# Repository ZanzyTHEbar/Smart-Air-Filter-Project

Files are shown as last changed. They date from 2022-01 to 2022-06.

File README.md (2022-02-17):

# :man_technologist:

# Purbright Controller

# :cat: Purbright Controller :cat2:

# Purbright Controller README

This repo is dedicated to the **Purbright Controller**, an automated system for purifying cat litter air.

# WHAT IS THIS PROJECT

This project is dedicated to designing PCB and programming files to bring the Purbright product to mass manufacturing.

# Things to Do

**__Hardware__**

- [x] Formulate project as PlatformIO
- [x] Integrate the PCB schematic layout
- [x] Integrate a BOM parts list for PCB
- [x] Integrate a Pick and Place file
- [ ] Integrate Panelised PCB gerber files
- [ ] Integrate SPI SRAM chip instead of SD Card
- [ ] Integrate speakers for audio feedback

**__Software__**

- [x] Implement proper memory management
- [ ] Implement proper error handling&logging
- [ ] Implement proper documentation
- [ ] Implement proper debugging for testing
- [ ] Add custom sounds for speakers
- [x] implement code as proper custom library
- [ ] implement dual core system archtecture
        --> Networking on one core and Application code on the other (esp32 is dual core)

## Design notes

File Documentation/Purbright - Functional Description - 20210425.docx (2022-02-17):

This document serves to describe the necessary functionality of the electronics that control the Purfect cat litter box.

# 1. Overview

The device filters dirty air by drawing air from the cat litter box by means of a Venturi. The water circulation flow is generated with a pump that pumps from a water reservoir back into the same reservoir. The venturi is located on the high-pressure side of the pump (output). The pump is activated when motion is detected. The pump stops automatically after a certain set time. When the manual mode is selected, the pump runs continuously.
The touch buttons are:
a. 1 button. ON/OFF switching
b. 2 buttons +/-. menu scrolling and raising/lowering automatic ON-time.

c. 1 button: selection between auto/man or settings menu after long press.

# 2. Components

a. Water pump (preferably a 5VDC version)
b. Venturi nozzle
c. Motion detection sensor
d. PCB with relay for the water pump
e. 4 touch sensors for menu control
f. NeoPixel LED for menu indication
g. speaker

# 3. Electric Diagram

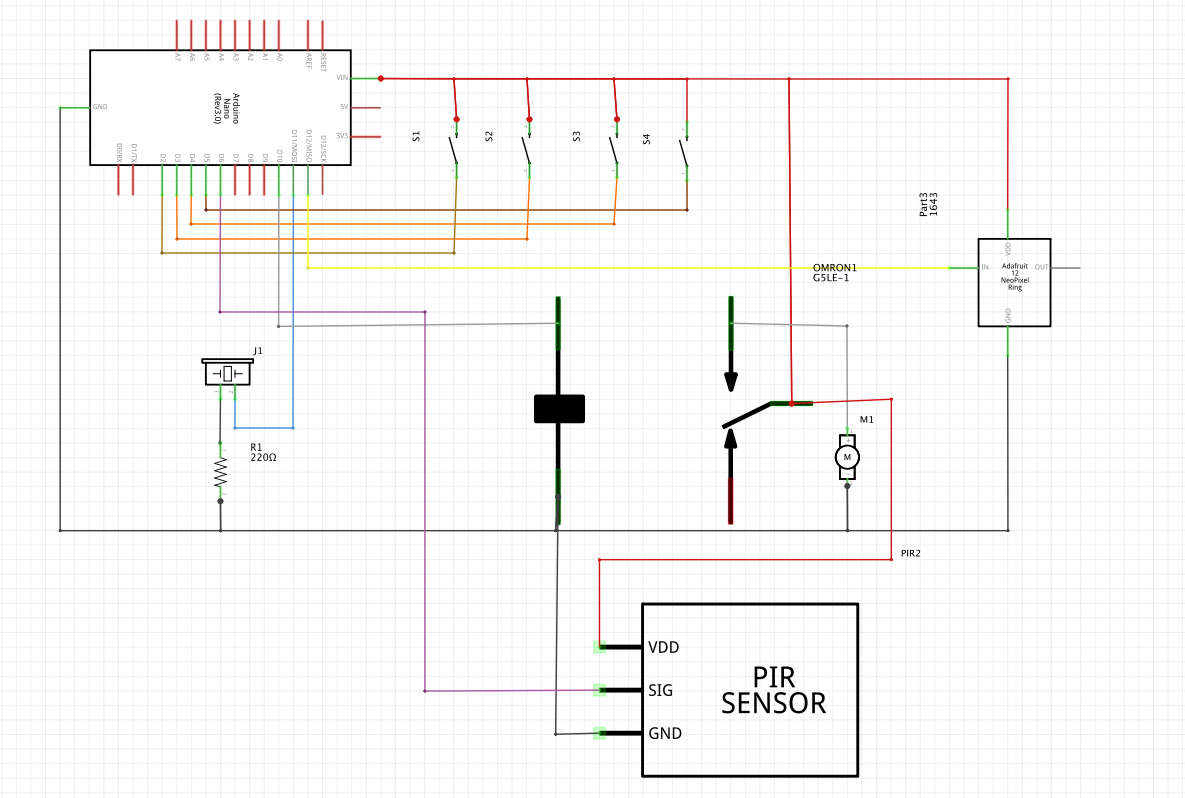
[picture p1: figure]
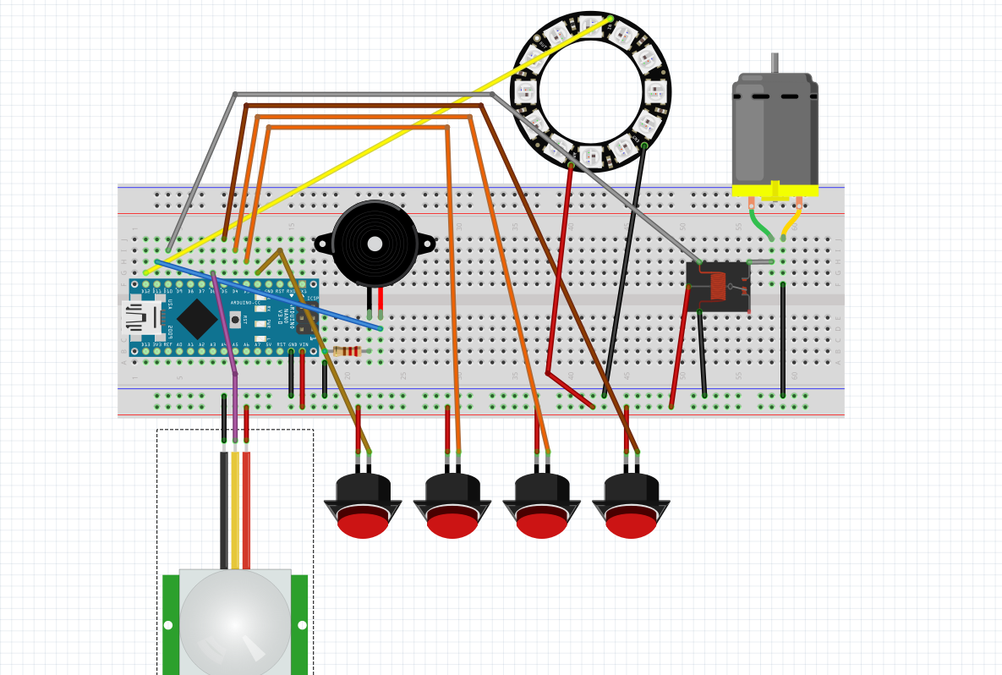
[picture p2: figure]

# 4. Shell

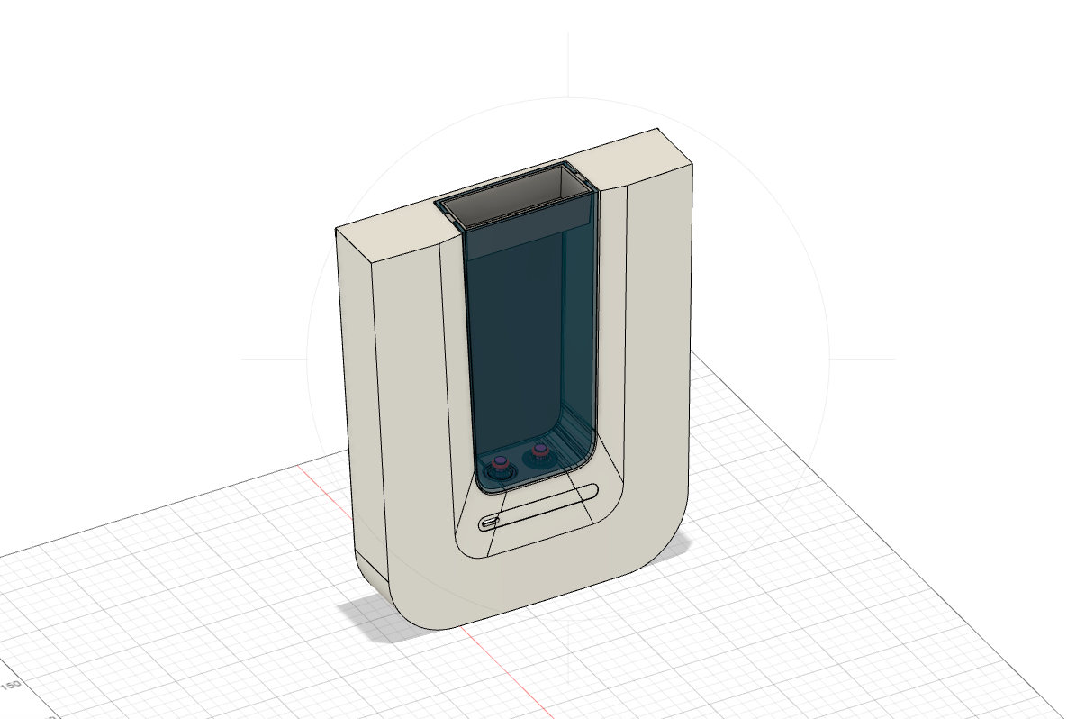
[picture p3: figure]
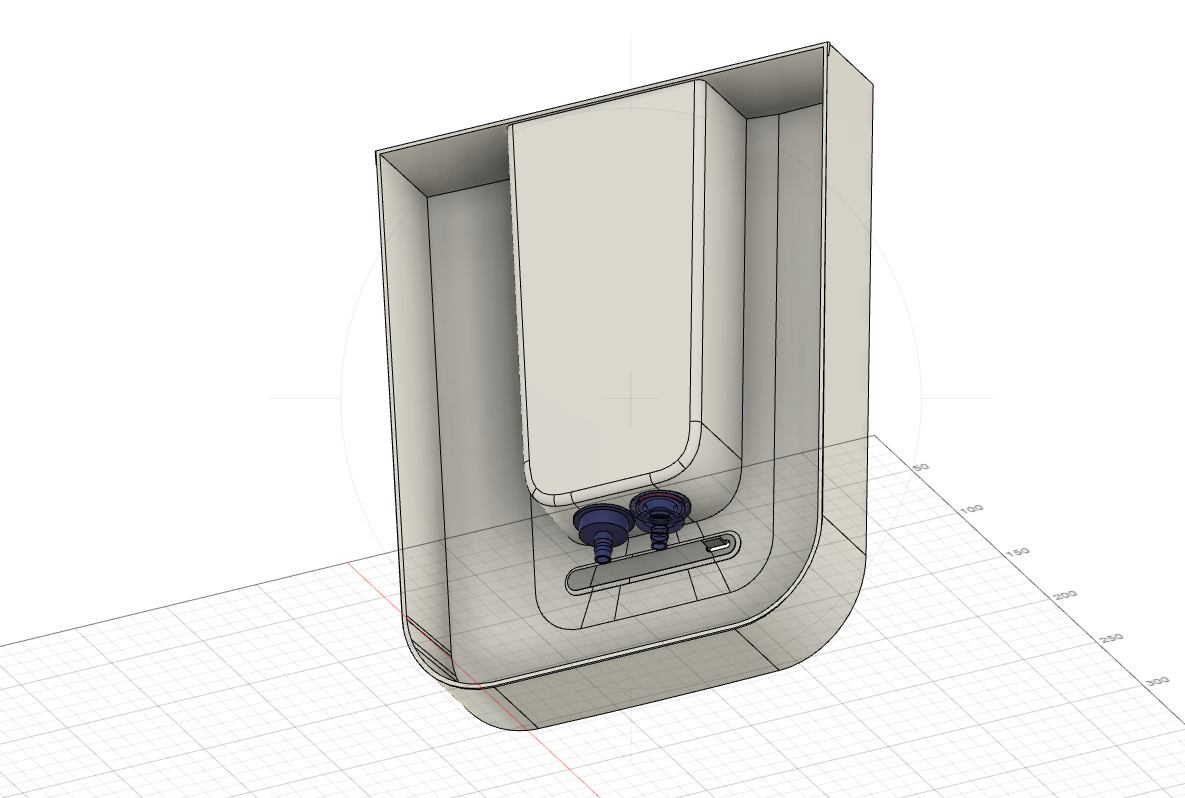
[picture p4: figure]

Location of touch buttons

Location of NeoPixel

# 5. Specifications

a. All components external to the PCB should be easily replaceable with a connector (Touch buttons, NeoPixel, Motion Sensor)
b. Power rating should be 5VDC.
c. An extra USB-C should be added for the power supply since the onboard USB-C cannot provide enough current for the water pump.
d. The possibility to update the device is required. (SD > Bluetooth > Wifi) The PCB should probably have the need for an (integrated) SD card. This would also allow for a storage of sound clips.
e. The capacitive touch buttons are located on the inside of the shell.

# 6. Extra Remarks

a. The current project is based on a Seeeduino/Arduino Nano but any suggestions is welcome. Arduino was chosen for the programmability.
b. Programming can be done by us if the Arduino technology is chosen. If not, when cheaper solution is provided, this document will be updated with a more extensive description of the workflow.
c. If for CE approval a hardware ON/OFF (vs the soft ON/OFF), the please include it.
d. The project was conceptualized with Arduino and

Purbright BV Vaderlandstraat 37, B-2610 Wilrijk, Belgium | VAT: BE 0750.606.388 M: +32 477 28 00 77 | E: hello@purbright.com | www.purbright.com

Functional Description Electronics

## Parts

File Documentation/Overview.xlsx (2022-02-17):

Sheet: Parts
 |  |  |  |  | 17 | 49.10 €
Group | Part | Brand | Model | Price | Qty | Tot | Supplier | Comments
Electronic | Board | Seeeduino Nano | SS-102010268 | 8.95 € | 1 | 8.95 € | www.kiwi-electronics.nl
Electronic | Relay | Grove | SS-103020005 | 3.50 € | 1 | 3.50 € | www.kiwi-electronics.nl
Electronic | LED | NeoPixel Ring | ADA-1643 | 8.95 € | 1 | 8.95 € | www.kiwi-electronics.nl
Electronic | Motion Sensor | Grove | SS-101020353 | 5.95 € | 1 | 5.95 € | www.kiwi-electronics.nl | PIR Mini
Electronic | Touch Sensor | Grove | SS-101020037 | 4.95 € | 4 | 19.80 € | www.kiwi-electronics.nl
Electronic | Speaker |  | ADA-1891 | 1.95 € | 1 | 1.95 € |  | Thin Plastic Speaker with Wires - 8 ohm 0.25W
Electronic | Pump |  |  |  | 1 | 0.00 € |  | 3-6V RC Water Pump
Water | Tubes |  |  |  |  | 0.00 €
Water | T-Connection |  |  |  | 1 | 0.00 € |  | This needs to be a venturi
Water | O-ring |  |  |  | 2 | 0.00 € |  | Reservoir closing
Water | Spring |  |  |  | 2 | 0.00 € |  | Reservoir closing
Water | Closing Pin |  |  |  | 2 | 0.00 € |  | Reservoir closing
 |  |  |  |  |  | 0.00 €
 |  |  |  |  |  | 0.00 €
 |  |  |  |  |  | 0.00 €
 |  |  |  |  |  | 0.00 €
 |  |  |  |  |  | 0.00 €
 |  |  |  |  |  | 0.00 €
 |  |  |  |  |  | 0.00 €
 |  |  |  |  |  | 0.00 €
 |  |  |  |  |  | 0.00 €
 |  |  |  |  |  | 0.00 €
 |  |  |  |  |  | 0.00 €
 |  |  |  |  |  | 0.00 €
 |  |  |  |  |  | 0.00 €
 |  |  |  |  |  | 0.00 €
 |  |  |  |  |  | 0.00 €
 |  |  |  |  |  | 0.00 €
 |  |  |  |  |  | 0.00 €
 |  |  |  |  |  | 0.00 €
 |  |  |  |  |  | 0.00 €
 |  |  |  |  |  | 0.00 €
 |  |  |  |  |  | 0.00 €
 |  |  |  |  |  | 0.00 €
 |  |  |  |  |  | 0.00 €
 |  |  |  |  |  | 0.00 €
 |  |  |  |  |  | 0.00 €
 |  |  |  |  |  | 0.00 €
 |  |  |  |  |  | 0.00 €
 |  |  |  |  |  | 0.00 €
 |  |  |  |  |  | 0.00 €
 |  |  |  |  |  | 0.00 €
 |  |  |  |  |  | 0.00 €
 |  |  |  |  |  | 0.00 €
 |  |  |  |  |  | 0.00 €
 |  |  |  |  |  | 0.00 €
 |  |  |  |  |  | 0.00 €
 |  |  |  |  |  | 0.00 €
 |  |  |  |  |  | 0.00 €
 |  |  |  |  |  | 0.00 €
 |  |  |  |  |  | 0.00 €
 |  |  |  |  |  | 0.00 €
 |  |  |  |  |  | 0.00 €
 |  |  |  |  |  | 0.00 €
 |  |  |  |  |  | 0.00 €
 |  |  |  |  |  | 0.00 €
 |  |  |  |  |  | 0.00 €
 |  |  |  |  |  | 0.00 €
 |  |  |  |  |  | 0.00 €
 |  |  |  |  |  | 0.00 €
 |  |  |  |  |  | 0.00 €
 |  |  |  |  |  | 0.00 €
 |  |  |  |  |  | 0.00 €
 |  |  |  |  |  | 0.00 €
 |  |  |  |  |  | 0.00 €
 |  |  |  |  |  | 0.00 €
 |  |  |  |  |  | 0.00 €
 |  |  |  |  |  | 0.00 €
 |  |  |  |  |  | 0.00 €
 |  |  |  |  |  | 0.00 €
 |  |  |  |  |  | 0.00 €
 |  |  |  |  |  | 0.00 €
 |  |  |  |  |  | 0.00 €
 |  |  |  |  |  | 0.00 €
 |  |  |  |  |  | 0.00 €
 |  |  |  |  |  | 0.00 €
 |  |  |  |  |  | 0.00 €
 |  |  |  |  |  | 0.00 €
 |  |  |  |  |  | 0.00 €
 |  |  |  |  |  | 0.00 €
 |  |  |  |  |  | 0.00 €
 |  |  |  |  |  | 0.00 €
 |  |  |  |  |  | 0.00 €
 |  |  |  |  |  | 0.00 €
 |  |  |  |  |  | 0.00 €
 |  |  |  |  |  | 0.00 €
 |  |  |  |  |  | 0.00 €
 |  |  |  |  |  | 0.00 €
 |  |  |  |  |  | 0.00 €
 |  |  |  |  |  | 0.00 €
 |  |  |  |  |  | 0.00 €
 |  |  |  |  |  | 0.00 €
 |  |  |  |  |  | 0.00 €
 |  |  |  |  |  | 0.00 €
 |  |  |  |  |  | 0.00 €
 |  |  |  |  |  | 0.00 €
 |  |  |  |  |  | 0.00 €
 |  |  |  |  |  | 0.00 €
 |  |  |  |  |  | 0.00 €
 |  |  |  |  |  | 0.00 €
 |  |  |  |  |  | 0.00 €
 |  |  |  |  |  | 0.00 €
 |  |  |  |  |  | 0.00 €
 |  |  |  |  |  | 0.00 €
 |  |  |  |  |  | 0.00 €
 |  |  |  |  |  | 0.00 €
 |  |  |  |  |  | 0.00 €
 |  |  |  |  |  | 0.00 €
 |  |  |  |  |  | 0.00 €

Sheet: IO
IO | Description | Type | Tech | Comment
IN | Motion Detection | Digitial
IN | Button 1: On/Off | Digitial | Capacitive?
IN | Button 2: Auto/man | Digitial | Capacitive?
IN | Button 3: + | Digitial | Capacitive?
IN | Button 4: - | Digitial | Capacitive?
OUT | Relay? | Digital |  | for 3-6V pump
OUT | NeoPixel |  |  | State indication
OUT | Speaker

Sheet: FDS
General
After detection of motion, the device starts a timed pump to pull water from the reservoir. This water gets mixed with air from the box that gets sucked in with a venturi.
This water -air mixture gets pumped back into the reservoir.
Startup
1. When the device is connected into the power socket, a power LED turns on.
2. With the ON/OFF button the device is activated and goes into automatic mode.
3. In automatic mode, motion is detected and a timed pump starts.
3.1. When motion is detected, another LED indicates the presence
3.2. During operation, a 3rd LED indicates wether the pump is on or off
4. With the Man/AUT button, the device can be put in manual mode where the pump is in continuous operation
5. By pressing the '+' button, the devices indicates the time settings and by pressing it again, time can be added (example: in blocks of 2m) to the automtic mode.
6. By pressing the '-' button, the devices indicates the time settings and by pressing it again, time can be subtracted (example: in blocks of 2m) from the automtic mode.
Notes
5&6 keep the operation mode going

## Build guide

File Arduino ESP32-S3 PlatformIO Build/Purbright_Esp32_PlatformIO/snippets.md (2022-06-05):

# HTML Snippets

```html
<div class="container">
    <div class="row">
        <div class="col-md-12">
            <h1>Hello World</h1>
        </div>
    </div>
</div>
```

## Calculate the range of Wifi signal strength

´´´txt
Signal transmission in ft^2 = ((dBm + 4,000) - 2,000) / 42.7

4,000 = nominal base dB of average consumer grade WIFI antenna
2,000 = Nominal base dB of peak signal interference
42.7 = a constant for conversion to square feet
´´´

```cpp
int signal_range = ((dBm + 4,000) - 2,000) / 42.7;

WiFi.setOutputPower(dBm);
From the point of view of the client:
a: How low is to low - when is the client not able to see the server
b: How close to this lowest point are we willing to go?

1. Client tells the server when it needs a stronger signal - do this in levels
2. Server lowers signal by a certain value each time frame 
3. Every x amount of time based on how long device can be without connection - it will pulse the signal at max sending out a wake up call to devices that have potentially lost connection
```

```cpp
if (!PRODUCTION) {
  // do development stuff
}
```

## Useful Links

[Wifi QR code generator](https://qifi.org/)

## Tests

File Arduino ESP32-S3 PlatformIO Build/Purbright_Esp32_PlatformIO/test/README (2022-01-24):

This directory is intended for PlatformIO Unit Testing and project tests.

Unit Testing is a software testing method by which individual units of
source code, sets of one or more MCU program modules together with associated
control data, usage procedures, and operating procedures, are tested to
determine whether they are fit for use. Unit testing finds problems early
in the development cycle.

More information about PlatformIO Unit Testing:
- https://docs.platformio.org/page/plus/unit-testing.html

pio\build\esp32dev\src\main.cpp.o:main.cpp:(.text._ZN20ESPAsync_WiFiManager11connectWifiERK6StringS2_+0x0): first defined here
.pio\build\esp32dev\lib142\libPurBrightLib.a(neopixel.cpp.o): In function `ESPAsync_WiFiManager::reconnectWifi()':
neopixel.cpp:(.text._ZN20ESPAsync_WiFiManager13reconnectWifiEv+0x0): multiple definition of `ESPAsync_WiFiManager::reconnectWifi()'

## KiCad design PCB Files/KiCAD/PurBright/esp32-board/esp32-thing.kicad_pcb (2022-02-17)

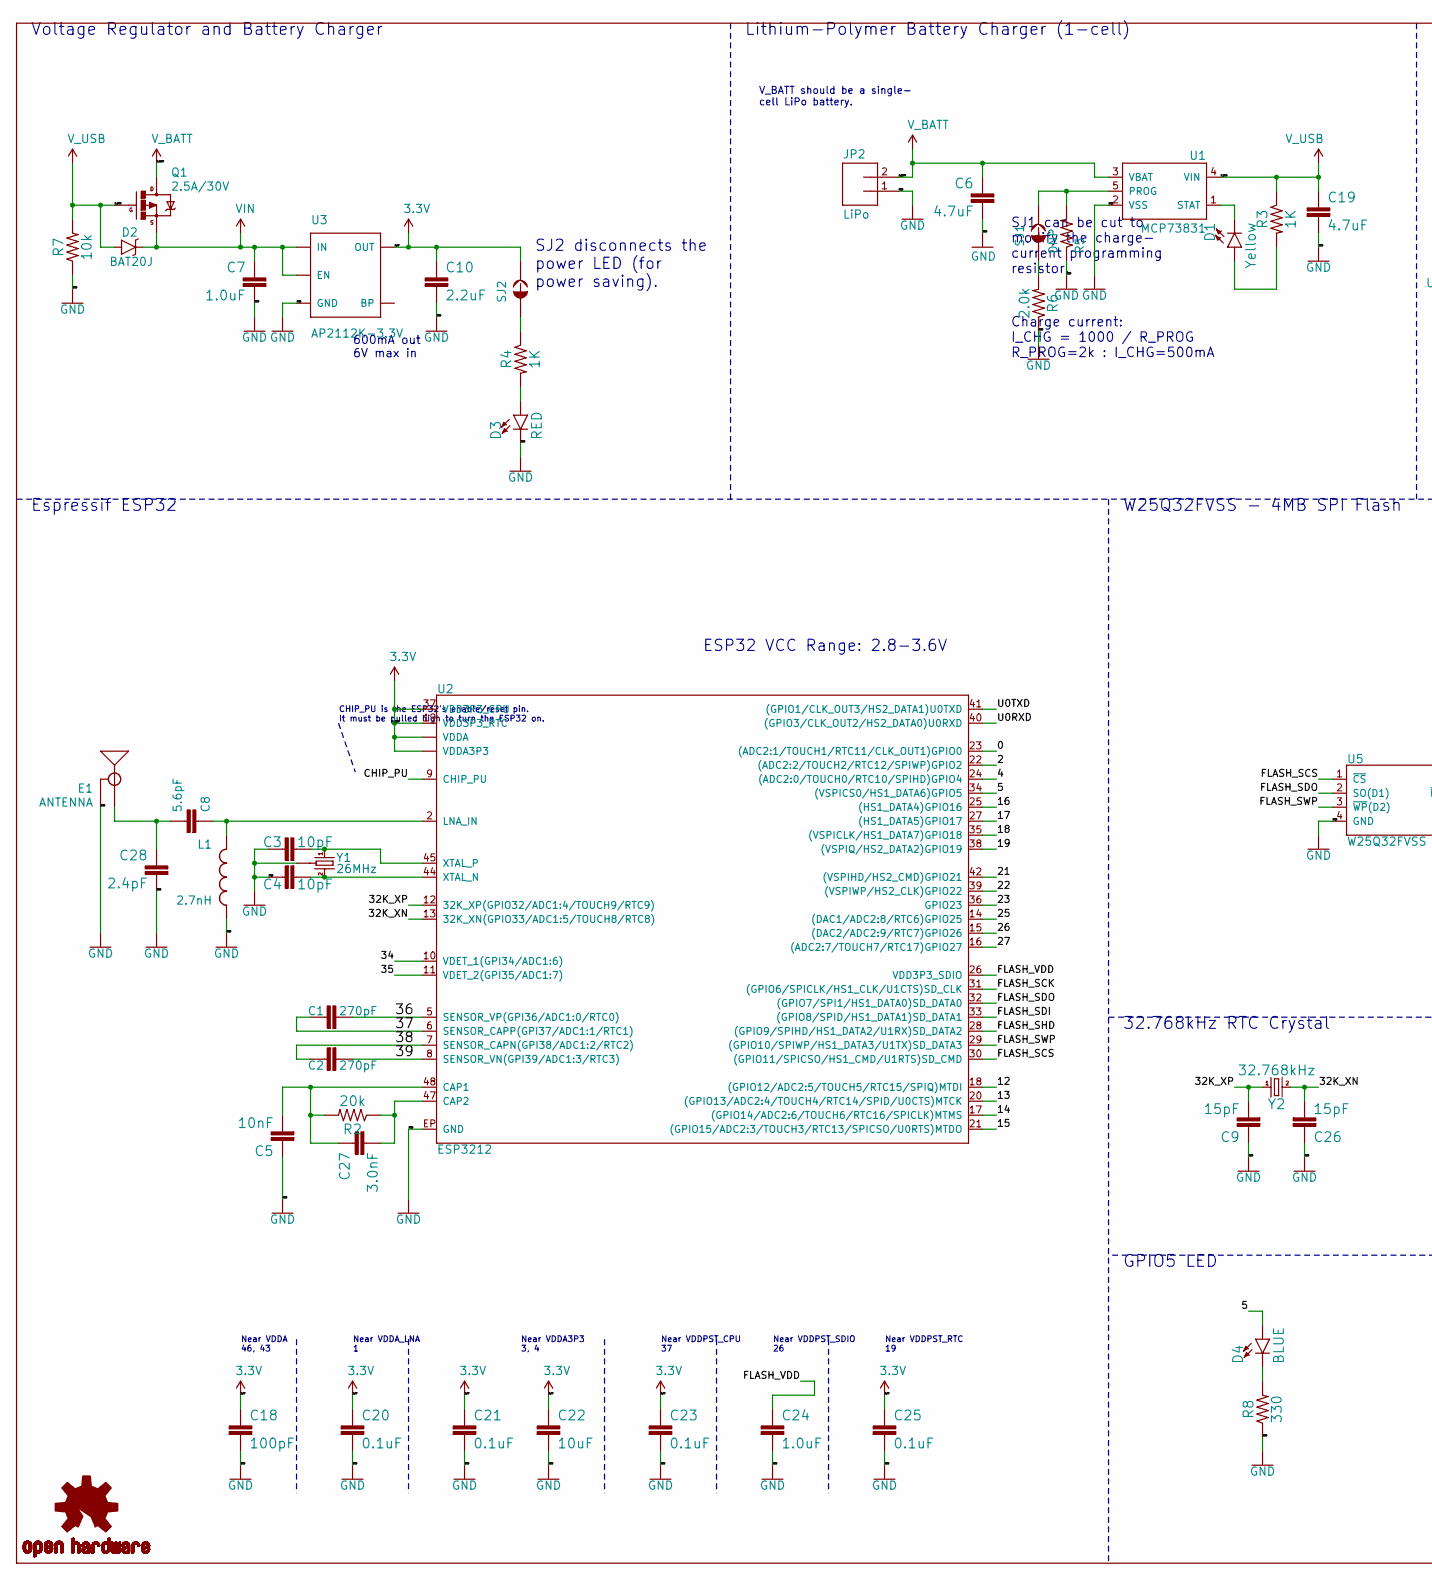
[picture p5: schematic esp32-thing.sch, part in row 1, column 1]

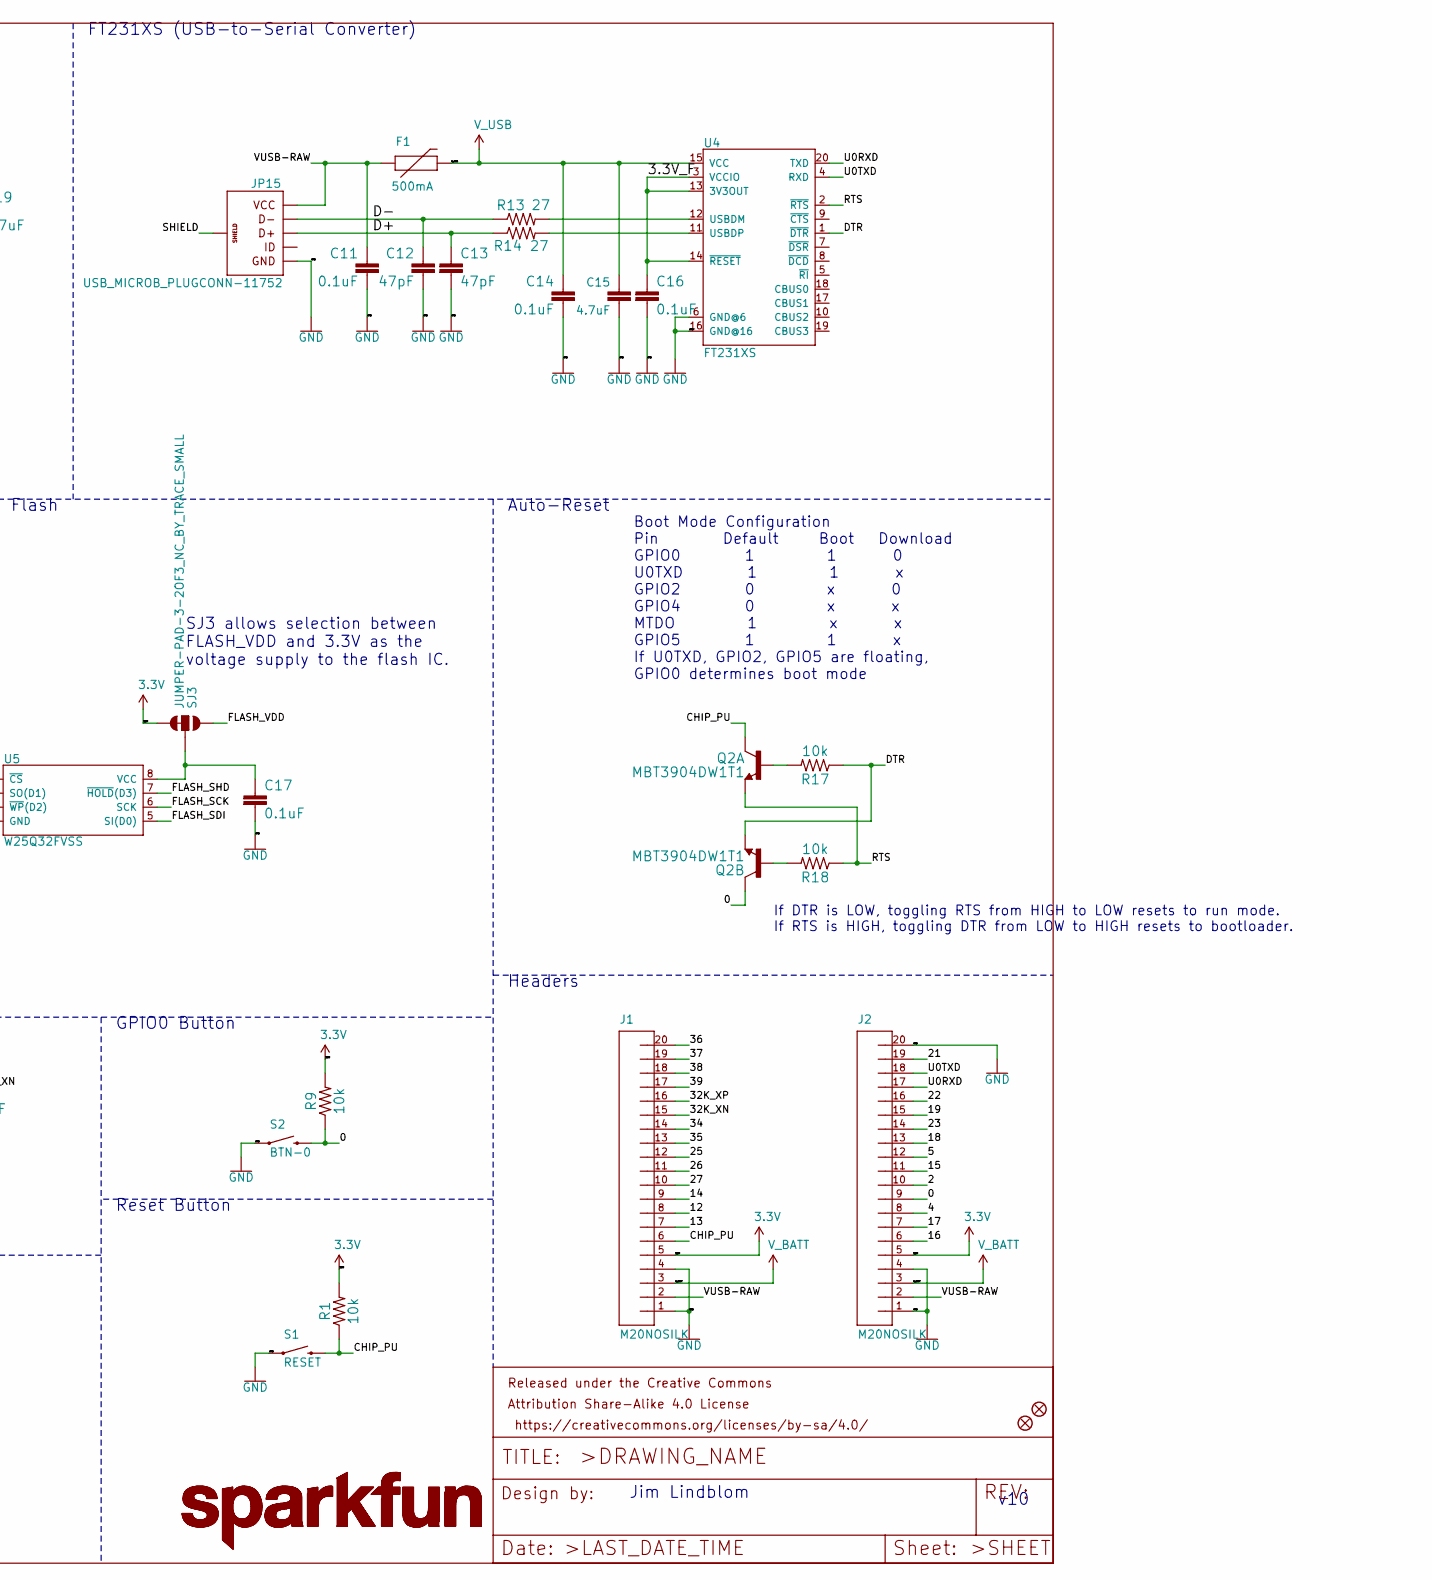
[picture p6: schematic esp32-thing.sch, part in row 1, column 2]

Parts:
C1, C2: 270pF; 0603
C3, C4: 10pF; 0603
C5: 10nF; 0603
C6, C19: 4.7uF; 0603
C7: 1.0uF; 0805
C8: 5.6pF; 0603
C9, C26: 15pF; 0603
C10: 2.2uF; 0603
C11, C14, C16, C17, C20, C21, C23, C25: 0.1uF; 0603
C12, C13: 47pF; 0603
C15: 4.7uF; 0603-CAP
C18: 100pF; 0603
C22: 10uF; 0603
C24: 1.0uF; 0603
C27: 3.0nF; 0603
C28: 2.4pF; 0603
D1: Yellow; LED-0603
D2: BAT20J; SOD-323
D3: RED; LED-0603
D4: BLUE; LED-0603
E1: ANTENNA; TRACE_ANTENNA_2.4GHZ_25.7MM_TUNED
F1: 500mA; PTC-1206
FD1, FD2: FIDUCIALUFIDUCIAL; MICRO-FIDUCIAL
FRAME1: FRAME-LEDGER; CREATIVE_COMMONS
J1, J2: M20NOSILK; 1X20_NOSILK
JP2: LiPo; JST-2-PTH
JP15: USB_MICROB_PLUGCONN-11752; USB-B-MICRO-SMD_V03
L1: 2.7nH; 0603
LOGO1, LOGO3: SFE_LOGO_NAME.2_INCH; SFE_LOGO_NAME_.2
LOGO2: OSHW-LOGOMINI; OSHW-LOGO-MINI
Q1: 2.5A/30V; SOT23-3
Q2: MBT3904DW1T1; SC70-6
R1, R7, R9, R17, R18: 10k; 0603
R2: 20k; 0603
R3, R4: 1K; 0603
R5: DNP; 1_6W-RES
R6: 2.0k; 0603
R8: 330; 0603
R13, R14: 27; 0603
S1: RESET; TACTILE_SWITCH_SMD_4.6X2.8MM
S2: BTN-0; TACTILE_SWITCH_SMD_4.6X2.8MM
SJ1, SJ2: JUMPER-PAD-2-NC_BY_TRACE; PAD-JUMPER-2-NC_BY_TRACE_YES_SILK
SJ3: JUMPER-PAD-3-2OF3_NC_BY_TRACE_SMALL; PAD-JUMPER-3-2OF3_NC_BY_TRACE_YES_SILK_FULL_BOX
U1: MCP73831; SOT23-5
U2: ESP3212; QFN48-0.4MM
U3: AP2112K-3.3V; SOT23-5
U4: FT231XS; SSOP20_L
U5: W25Q32FVSS; SOIC-8
Y1: 26MHz; CRYSTAL-SMD-3.2X2.5
Y2: 32.768kHz; CRYSTAL-SMD-3.2X1.5MM

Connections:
3.3V: C10.1, C18.1, C20.1, C21.1, C22.1, C23.1, C25.1, J1.5, J2.5, R1.2, R9.2, SJ2.2, SJ3.3, U2.1 (VDDA), U2.3 (VDDA3P3), U2.4 (VDDA3P3), U2.19 (VDD3P3_RTC), U2.37 (VDD3P3_CPU), U2.43 (VDDA), U2.46 (VDDA), U3.5 (OUT)
/0: J2.9, Q2.6 (C), R9.1, S2.3 (2), S2.4 (2), U2.23 ((ADC2:1/TOUCH1/RTC11/CLK_OUT1)GPIO0)
/2: J2.10, U2.22 ((ADC2:2/TOUCH2/RTC12/SPIWP)GPIO2)
/3.3V_F: C16.1, U4.3 (VCCIO), U4.13 (3V3OUT), U4.14 (~RESET)
/4: J2.8, U2.24 ((ADC2:0/TOUCH0/RTC10/SPIHD)GPIO4)
/5: D4.A, J2.12, U2.34 ((VSPICS0/HS1_DATA6)GPIO5)
/12: J1.8, U2.18 ((GPIO12/ADC2:5/TOUCH5/RTC15/SPIQ)MTDI)
/13: J1.7, U2.20 ((GPIO13/ADC2:4/TOUCH4/RTC14/SPID/U0CTS)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)
/14: J1.9, U2.17 ((GPIO14/ADC2:6/TOUCH6/RTC16/SPICLK)MTMS)
/15: J2.11, U2.21 ((GPIO15/ADC2:3/TOUCH3/RTC13/SPICSO/U0RT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)
/16: J2.6, U2.25 ((HS1_DATA4)GPIO16)
/17: J2.7, U2.27 ((HS1_DATA5)GPIO17)
/18: J2.13, U2.35 ((VSPICLK/HS1_DATA7)GPIO18)
/19: J2.15, U2.38 ((VSPIQ/HS2_DATA2)GPIO19)
/21: J2.19, U2.42 ((VSPIHD/HS2_CMD)GPIO21)
/22: J2.16, U2.39 ((VSPIWP/HS2_CLK)GPIO22)
/23: J2.14, U2.36 (GPIO23)
/25: J1.12, U2.14 ((DAC1/ADC2:8/RTC6)GPIO25)
/26: J1.11, U2.15 ((DAC2/ADC2:9/RTC7)GPIO26)
/27: J1.10, U2.16 ((ADC2:7/TOUCH7/RTC17)GPIO27)
/32K_XN: C26.2, J1.15, U2.13 (32K_XN(GPIO33/ADC1:5/TOUCH8/RTC8)), Y2.P$2 (2)
/32K_XP: C9.2, J1.16, U2.12 (32K_XP(GPIO32/ADC1:4/TOUCH9/RTC9)), Y2.P$1 (1)
/34: J1.14, U2.10 (VDET_1(GPI34/ADC1:6))
/35: J1.13, U2.11 (VDET_2(GPI35/ADC1:7))
/36: C1.2, J1.20, U2.5 (SENSOR_VP(GPI36/ADC1:0/RTC0))
/37: C1.1, J1.19, U2.6 (SENSOR_CAPP(GPI37/ADC1:1/RTC1))
/38: C2.1, J1.18, U2.7 (SENSOR_CAPN(GPI38/ADC1:2/RTC2))
/39: C2.2, J1.17, U2.8 (SENSOR_VN(GPI39/ADC1:3/RTC3))
/CHIP_PU: J1.6, Q2.3 (C), R1.1, S1.3 (2), S1.4 (2), U2.9 (CHIP_PU)
/D+: C13.1, JP15.D+, R14.1
/D-: C12.1, JP15.D-, R13.1
/DTR: Q2.1 (E), R17.1, U4.1 (~DTR)
/FLASH_SCK: U2.31 ((GPIO6/SPICLK/HS1_CLK/U1CTS)SD_CLK), U5.6 (SCK)
/FLASH_SCS: U2.30 ((GPIO11/SPICSO/HS1_CMD/U1RTS)SD_CMD), U5.1 (~CS~)
/FLASH_SDI: U2.33 ((GPIO8/SPID/HS1_DATA1)SD_DATA1), U5.5 (SI(D0))
/FLASH_SDO: U2.32 ((GPIO7/SPI1/HS1_DATA0)SD_DATA0), U5.2 (SO(D1))
/FLASH_SHD: U2.28 ((GPIO9/SPIHD/HS1_DATA2/U1RX)SD_DATA2), U5.7 (~HOLD~(D3))
/FLASH_SWP: U2.29 ((GPIO10/SPIWP/HS1_DATA3/U1TX)SD_DATA3), U5.3 (~WP~(D2))
/FLASH_VDD: C24.1, SJ3.1, U2.26 (VDD3P3_SDIO)
/RTS: Q2.4 (E), R18.1, U4.2 (~RTS)
/SHIELD: JP15.SHIELD1 (SHIELD), JP15.SHIELD2 (SHIELD), JP15.SHIELD3 (SHIELD)
/U0RXD: J2.17, U2.40 ((GPIO3/CLK_OUT2/HS2_DATA0)U0RXD), U4.20 (TXD)
/U0TXD: J2.18, U2.41 ((GPIO1/CLK_OUT3/HS2_DATA1)U0TXD), U4.4 (RXD)
/VUSB-RAW: C11.1, F1.1, J1.2, J2.2, JP15.VBUS (VCC)
GND: C3.1, C4.1, C5.1, C6.2, C7.2, C9.1, C10.2, C11.2, C12.2, C13.2, C14.2, C15.2, C16.2, C17.2, C18.2, C19.2, C20.2, C21.2, C22.2, C23.2, C24.2, C25.2, C26.1, C28.2, D3.C, E1.GND, E1.GND2 (GND), J1.1, J1.4, J2.1, J2.4, J2.20, JP2.1, JP15.GND, L1.2, R5.1, R6.1, R7.1, R8.1, S1.1, S1.2 (1), S2.1, S2.2 (1), U1.2 (VSS), U2.EP (GND), U3.2 (GND), U4.6 (GND@6), U4.16 (GND@16), U5.4 (GND), Y1.2 (GND), Y1.4 (GND)
unnamed: C3.2, U2.45 (XTAL_P), Y1.1
unnamed: C4.2, U2.44 (XTAL_N), Y1.3 (2)
unnamed: C8.1, L1.1, U2.2 (LNA_IN)
unnamed: C17.1, SJ3.2, U5.8 (VCC)
unnamed: C5.2, C27.1, R2.2, U2.48 (CAP1)
unnamed: C27.2, R2.1, U2.47 (CAP2)
unnamed: C8.2, C28.1, E1.ANT (SIGNAL)
unnamed: D1.A, R3.2
unnamed: D1.C, U1.1 (STAT)
unnamed: D3.A, R4.2
unnamed: D4.C, R8.2
unnamed: Q2.2 (B), R18.2
unnamed: Q2.5 (B), R17.2
unnamed: R4.1, SJ2.1
unnamed: R5.2, SJ1.2, U1.5 (PROG)
unnamed: R6.2, SJ1.1
unnamed: R13.2, U4.12 (USBDM)
unnamed: R14.2, U4.11 (USBDP)
VIN: C7.1, D2.C, Q1.2 (S), U3.1 (IN), U3.3 (EN)
V_BATT: C6.1, J1.3, J2.3, JP2.2, Q1.3 (D), U1.3 (VBAT)
V_USB: C14.1, C15.1, C19.1, D2.A, F1.2, Q1.1 (G), R3.1, R7.2, U1.4 (VIN), U4.15 (VCC)

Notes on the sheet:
Boot Mode Configuration Pin Default Boot Download GPIO0 1 1 0 U0TXD 1 1 x GPIO2 0 x 0 GPIO4 0 x x MTDO 1 x x GPIO5 1 1 x If U0TXD, GPIO2, GPIO5 are floating, GPIO0 determines boot mode
FT231XS (USB-to-Serial Converter)
V_BATT should be a single- cell LiPo battery.
Charge current: I_CHG = 1000 / R_PROG R_PROG=2k : I_CHG=500mA
Voltage Regulator and Battery Charger
SJ1 can be cut to modify the charge- current programming resistor.
Lithium-Polymer Battery Charger (1-cell)
600mA out 6V max in
Auto-Reset
Near VDDA 46, 43
Near VDDA_LNA 1
Near VDDA3P3 3, 4
Near VDDPST_CPU 37
Near VDDPST_SDIO 26
Near VDDPST_RTC 19
Espressif ESP32
W25Q32FVSS - 4MB SPI Flash
32.768kHz RTC Crystal
GPIO0 Button
Reset Button
GPIO5 LED
Headers
v10
Jim Lindblom
ESP32 VCC Range: 2.8-3.6V
SJ3 allows selection between FLASH_VDD and 3.3V as the voltage supply to the flash IC.
SJ2 disconnects the power LED (for power saving).
If DTR is LOW, toggling RTS from HIGH to LOW resets to run mode. If RTS is HIGH, toggling DTR from LOW to HIGH resets to bootloader.
CHIP_PU is the ESP32's enable/reset pin. It must be pulled high to turn the ESP32 on.

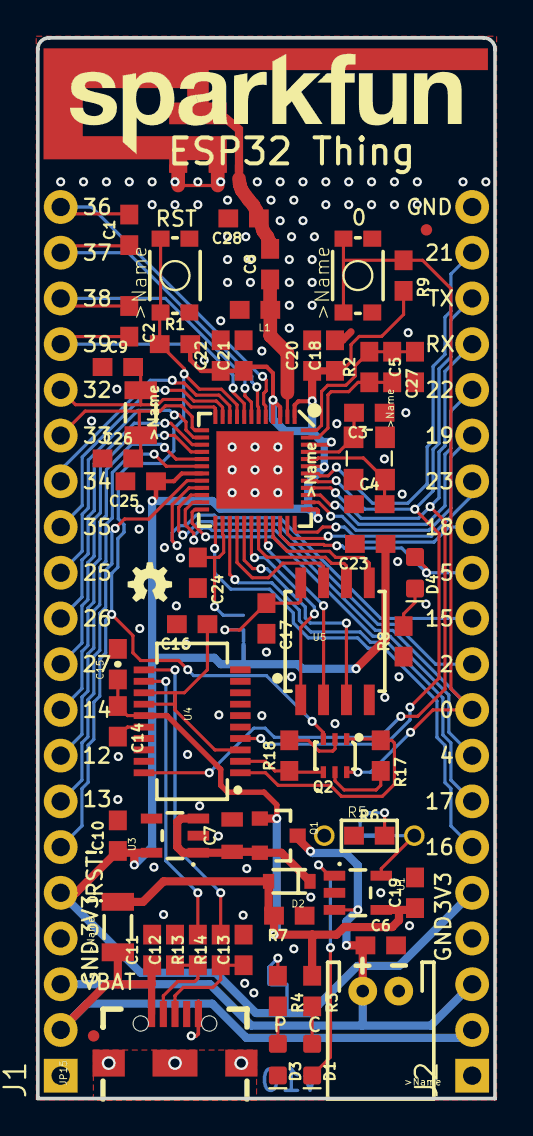
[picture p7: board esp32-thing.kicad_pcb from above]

Board: 2 copper layers, 25.4 x 58.9 mm, 72 parts (0 on the bottom side), 66 nets.

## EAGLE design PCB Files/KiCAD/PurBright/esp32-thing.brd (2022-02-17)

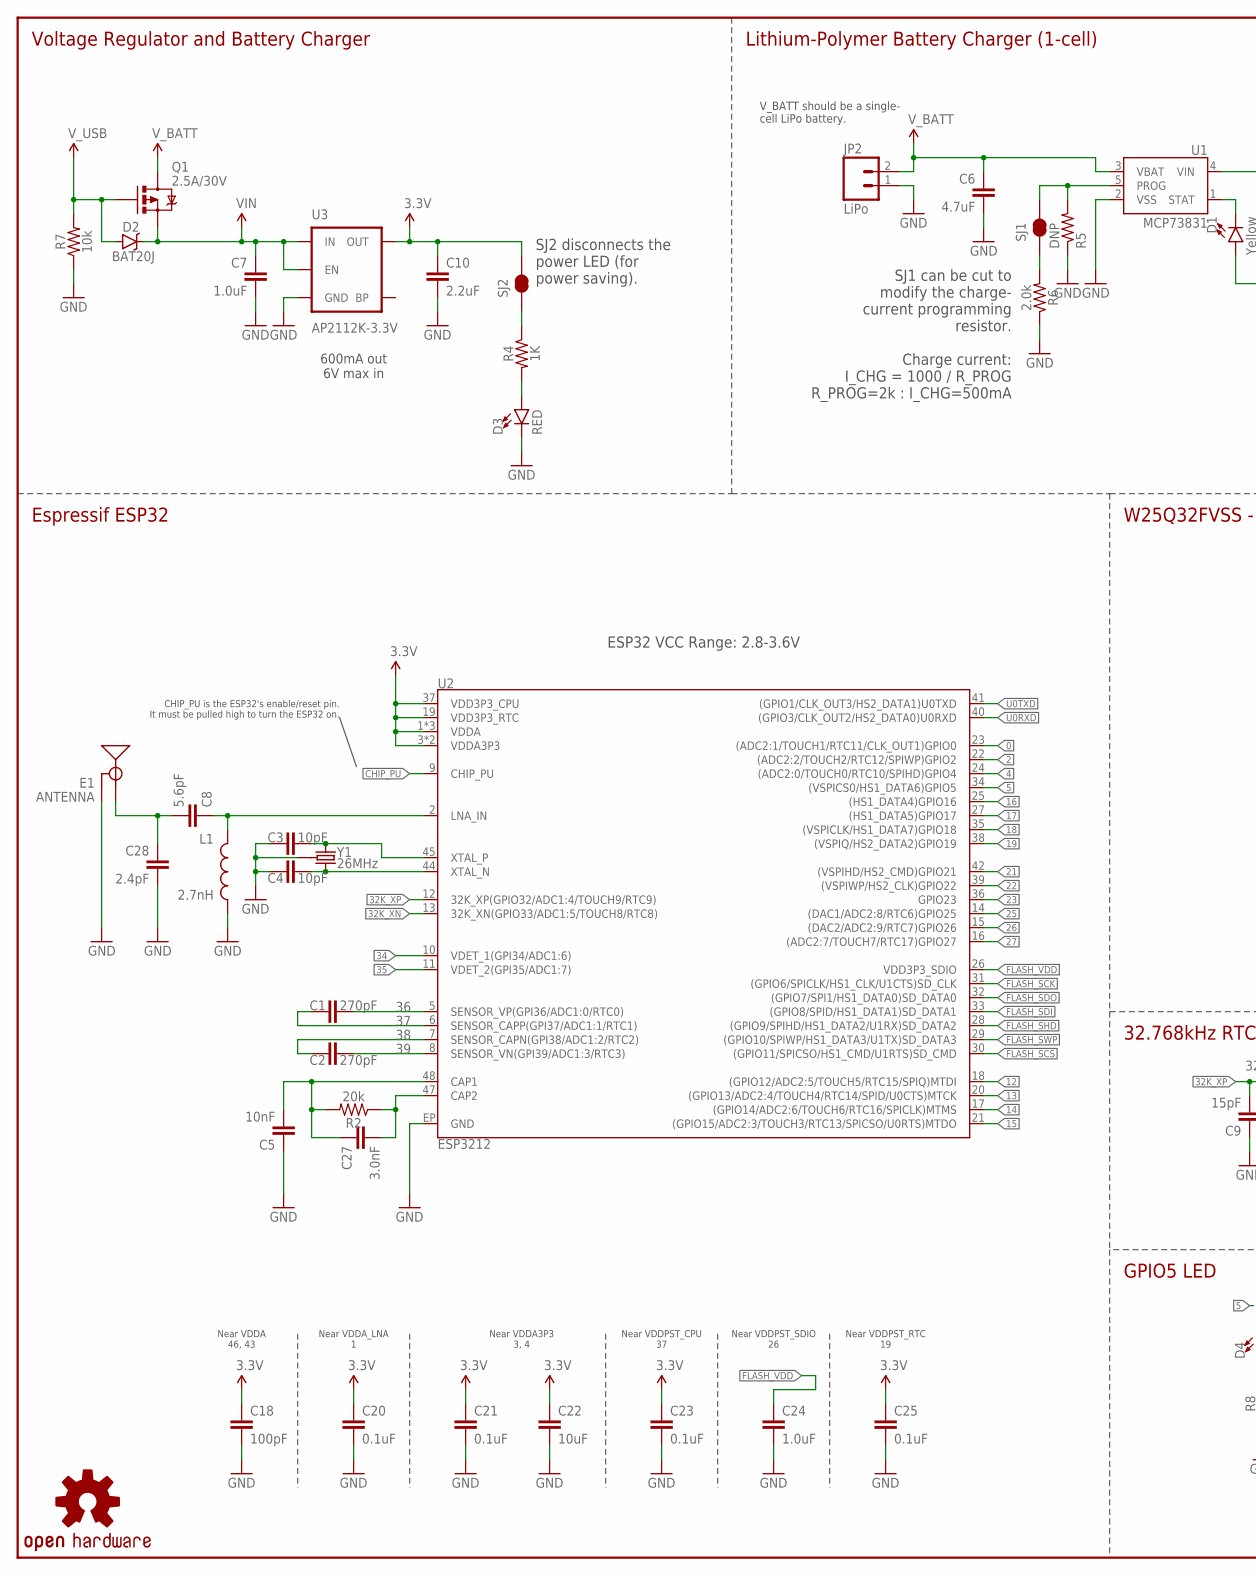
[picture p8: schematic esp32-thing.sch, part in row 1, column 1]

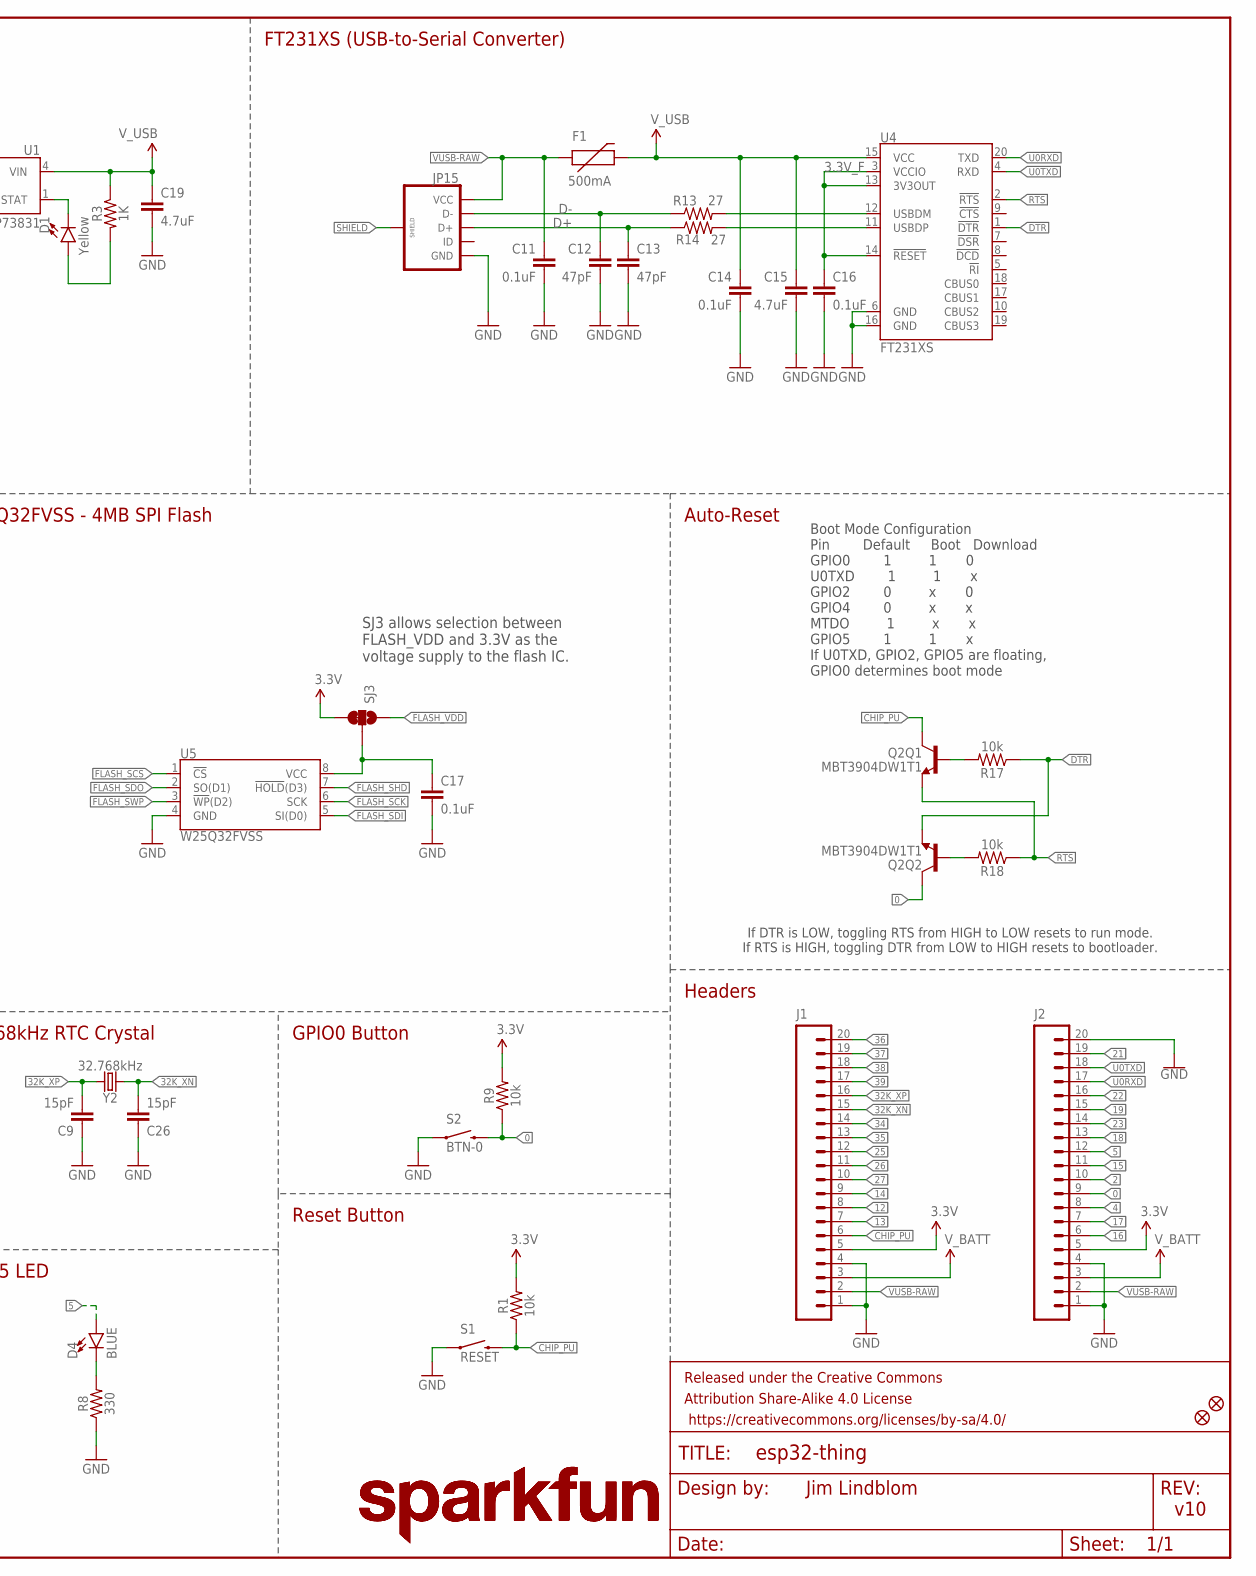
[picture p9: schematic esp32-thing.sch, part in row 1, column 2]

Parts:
C1, C2: 270pF; 0603
C3, C4: 10pF; 0603
C5: 10nF; 0603
C6, C19: 4.7uF; 0603
C7: 1.0uF; 0805
C8: 5.6pF; 0603
C9, C26: 15pF; 0603
C10: 2.2uF; 0603
C11, C14, C16, C17, C20, C21, C23, C25: 0.1uF; 0603
C12, C13: 47pF; 0603
C15: 4.7uF; 0603-CAP
C18: 100pF; 0603
C22: 10uF; 0603
C24: 1.0uF; 0603
C27: 3.0nF; 0603
C28: 2.4pF; 0603
D1: Yellow; LED-0603
D2: BAT20J; SOD-323
D3: RED; LED-0603
D4: BLUE; LED-0603
E1: ANTENNA; TRACE_ANTENNA_2.4GHZ_25.7MM_TUNED
F1: 500mA; PTC-1206
FD1, FD2: FIDUCIALUFIDUCIAL; MICRO-FIDUCIAL
FRAME1: FRAME-LEDGER; CREATIVE_COMMONS
J1, J2: M20NOSILK; 1X20_NOSILK
JP2: LiPo; JST-2-PTH
JP15: USB_MICROB_PLUGCONN-11752; USB-B-MICRO-SMD_V03
L1: 2.7nH; 0603
LOGO1, LOGO3: SFE_LOGO_NAME.2_INCH; SFE_LOGO_NAME_.2
LOGO2: OSHW-LOGOMINI; OSHW-LOGO-MINI
Q1: 2.5A/30V; SOT23-3
Q2: MBT3904DW1T1; SC70-6
R1, R7, R9, R17, R18: 10k; 0603
R2: 20k; 0603
R3, R4: 1K; 0603
R5: DNP; 1/6W-RES
R6: 2.0k; 0603
R8: 330; 0603
R13, R14: 27; 0603
S1: RESET; TACTILE_SWITCH_SMD_4.6X2.8MM
S2: BTN-0; TACTILE_SWITCH_SMD_4.6X2.8MM
SJ1, SJ2: JUMPER-PAD-2-NC_BY_TRACE; PAD-JUMPER-2-NC_BY_TRACE_YES_SILK
SJ3: JUMPER-PAD-3-2OF3_NC_BY_TRACE_SMALL; PAD-JUMPER-3-2OF3_NC_BY_TRACE_YES_SILK_FULL_BOX
U1: MCP73831; SOT23-5
U2: ESP3212; QFN48-0.4MM
U3: AP2112K-3.3V; SOT23-5
U4: FT231XS; SSOP20_L
U5: W25Q32FVSS; SOIC-8
Y1: 26MHz; CRYSTAL-SMD-3.2X2.5
Y2: 32.768kHz; CRYSTAL-SMD-3.2X1.5MM

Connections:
0: J2.9, Q2.6 (C), R9.1, S2.3 (2), S2.4 (2), U2.23 ((ADC2:1/TOUCH1/RTC11/CLK_OUT1)GPIO0)
2: J2.10, U2.22 ((ADC2:2/TOUCH2/RTC12/SPIWP)GPIO2)
3.3V: C10.1, C18.1, C20.1, C21.1, C22.1, C23.1, C25.1, J1.5, J2.5, R1.2, R9.2, SJ2.2, SJ3.3, U2.1 (VDDA), U2.3 (VDDA3P3), U2.4 (VDDA3P3), U2.19 (VDD3P3_RTC), U2.37 (VDD3P3_CPU), U2.43 (VDDA), U2.46 (VDDA), U3.5 (OUT)
3.3V_F: C16.1, U4.3 (VCCIO), U4.13 (3V3OUT), U4.14 (!RESET)
4: J2.8, U2.24 ((ADC2:0/TOUCH0/RTC10/SPIHD)GPIO4)
5: D4.A, J2.12, U2.34 ((VSPICS0/HS1_DATA6)GPIO5)
12: J1.8, U2.18 ((GPIO12/ADC2:5/TOUCH5/RTC15/SPIQ)MTDI)
13: J1.7, U2.20 ((GPIO13/ADC2:4/TOUCH4/RTC14/SPID/U0CTS)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)
14: J1.9, U2.17 ((GPIO14/ADC2:6/TOUCH6/RTC16/SPICLK)MTMS)
15: J2.11, U2.21 ((GPIO15/ADC2:3/TOUCH3/RTC13/SPICSO/U0RT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)
16: J2.6, U2.25 ((HS1_DATA4)GPIO16)
17: J2.7, U2.27 ((HS1_DATA5)GPIO17)
18: J2.13, U2.35 ((VSPICLK/HS1_DATA7)GPIO18)
19: J2.15, U2.38 ((VSPIQ/HS2_DATA2)GPIO19)
21: J2.19, U2.42 ((VSPIHD/HS2_CMD)GPIO21)
22: J2.16, U2.39 ((VSPIWP/HS2_CLK)GPIO22)
23: J2.14, U2.36 (GPIO23)
25: J1.12, U2.14 ((DAC1/ADC2:8/RTC6)GPIO25)
26: J1.11, U2.15 ((DAC2/ADC2:9/RTC7)GPIO26)
27: J1.10, U2.16 ((ADC2:7/TOUCH7/RTC17)GPIO27)
32K_XN: C26.2, J1.15, U2.13 (32K_XN(GPIO33/ADC1:5/TOUCH8/RTC8)), Y2.P$2 (2)
32K_XP: C9.2, J1.16, U2.12 (32K_XP(GPIO32/ADC1:4/TOUCH9/RTC9)), Y2.P$1 (1)
34: J1.14, U2.10 (VDET_1(GPI34/ADC1:6))
35: J1.13, U2.11 (VDET_2(GPI35/ADC1:7))
36: C1.2, J1.20, U2.5 (SENSOR_VP(GPI36/ADC1:0/RTC0))
37: C1.1, J1.19, U2.6 (SENSOR_CAPP(GPI37/ADC1:1/RTC1))
38: C2.1, J1.18, U2.7 (SENSOR_CAPN(GPI38/ADC1:2/RTC2))
39: C2.2, J1.17, U2.8 (SENSOR_VN(GPI39/ADC1:3/RTC3))
CAP_10N: C5.2, C27.1, R2.2, U2.48 (CAP1)
CHIP_PU: J1.6, Q2.3 (C), R1.1, S1.3 (2), S1.4 (2), U2.9 (CHIP_PU)
D+: C13.1, JP15.D+, R14.1
D-: C12.1, JP15.D-, R13.1
DTR: Q2.1 (E), R17.1, U4.1 (!DTR)
FLASH_SCK: U2.31 ((GPIO6/SPICLK/HS1_CLK/U1CTS)SD_CLK), U5.6 (SCK)
FLASH_SCS: U2.30 ((GPIO11/SPICSO/HS1_CMD/U1RTS)SD_CMD), U5.1 (!CS!)
FLASH_SDI: U2.33 ((GPIO8/SPID/HS1_DATA1)SD_DATA1), U5.5 (SI(D0))
FLASH_SDO: U2.32 ((GPIO7/SPI1/HS1_DATA0)SD_DATA0), U5.2 (SO(D1))
FLASH_SHD: U2.28 ((GPIO9/SPIHD/HS1_DATA2/U1RX)SD_DATA2), U5.7 (!HOLD!(D3))
FLASH_SWP: U2.29 ((GPIO10/SPIWP/HS1_DATA3/U1TX)SD_DATA3), U5.3 (!WP!(D2))
FLASH_VDD: C24.1, SJ3.1, U2.26 (VDD3P3_SDIO)
GND: C3.1, C4.1, C5.1, C6.2, C7.2, C9.1, C10.2, C11.2, C12.2, C13.2, C14.2, C15.2, C16.2, C17.2, C18.2, C19.2, C20.2, C21.2, C22.2, C23.2, C24.2, C25.2, C26.1, C28.2, D3.C, E1.GND, E1.GND2 (GND), J1.1, J1.4, J2.1, J2.4, J2.20, JP2.1, JP15.GND, L1.2, R5.1, R6.1, R7.1, R8.1, S1.1, S1.2 (1), S2.1, S2.2 (1), U1.2 (VSS), U2.EP (GND), U3.2 (GND), U4.6 (GND), U4.16 (GND), U5.4 (GND), Y1.2 (GND), Y1.4 (GND)
LNA_IN: C8.1, L1.1, U2.2 (LNA_IN)
unnamed: D4.C, R8.2
unnamed: D3.A, R4.2
unnamed: R4.1, SJ2.1
unnamed: C27.2, R2.1, U2.47 (CAP2)
unnamed: R13.2, U4.12 (USBDM)
unnamed: R14.2, U4.11 (USBDP)
unnamed: D1.C, U1.1 (STAT)
unnamed: Q2.5 (B), R17.2
unnamed: C17.1, SJ3.2, U5.8 (VCC)
unnamed: Q2.2 (B), R18.2
unnamed: C3.2, U2.45 (XTAL_P), Y1.1
unnamed: R5.2, SJ1.2, U1.5 (PROG)
unnamed: C4.2, U2.44 (XTAL_N), Y1.3 (2)
unnamed: R6.2, SJ1.1
unnamed: D1.A, R3.2
RTS: Q2.4 (E), R18.1, U4.2 (!RTS)
SHIELD: JP15.SHIELD1 (SHIELD), JP15.SHIELD2 (SHIELD), JP15.SHIELD3 (SHIELD)
TRACE_ANT: C8.2, C28.1, E1.ANT (SIGNAL)
U0RXD: J2.17, U2.40 ((GPIO3/CLK_OUT2/HS2_DATA0)U0RXD), U4.20 (TXD)
U0TXD: J2.18, U2.41 ((GPIO1/CLK_OUT3/HS2_DATA1)U0TXD), U4.4 (RXD)
VIN: C7.1, D2.C, Q1.2 (S), U3.1 (IN), U3.3 (EN)
VUSB-RAW: C11.1, F1.1, J1.2, J2.2, JP15.VBUS (VCC)
V_BATT: C6.1, J1.3, J2.3, JP2.2, Q1.3 (D), U1.3 (VBAT)
V_USB: C14.1, C15.1, C19.1, D2.A, F1.2, Q1.1 (G), R3.1, R7.2, U1.4 (VIN), U4.15 (VCC)

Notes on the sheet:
Boot Mode Configuration Pin Default Boot Download GPIO0 1 1 0 U0TXD 1 1 x GPIO2 0 x 0 GPIO4 0 x x MTDO 1 x x GPIO5 1 1 x If U0TXD, GPIO2, GPIO5 are floating, GPIO0 determines boot mode
FT231XS (USB-to-Serial Converter)
V_BATT should be a single- cell LiPo battery.
Charge current: I_CHG = 1000 / R_PROG R_PROG=2k : I_CHG=500mA
Voltage Regulator and Battery Charger
SJ1 can be cut to modify the charge- current programming resistor.
Lithium-Polymer Battery Charger (1-cell)
600mA out 6V max in
Auto-Reset
Near VDDA 46, 43
Near VDDA_LNA 1
Near VDDA3P3 3, 4
Near VDDPST_CPU 37
Near VDDPST_SDIO 26
Near VDDPST_RTC 19
Espressif ESP32
W25Q32FVSS - 4MB SPI Flash
32.768kHz RTC Crystal
GPIO0 Button
Reset Button
GPIO5 LED
Headers
v10
Jim Lindblom
ESP32 VCC Range: 2.8-3.6V
SJ3 allows selection between FLASH_VDD and 3.3V as the voltage supply to the flash IC.
SJ2 disconnects the power LED (for power saving).
If DTR is LOW, toggling RTS from HIGH to LOW resets to run mode. If RTS is HIGH, toggling DTR from LOW to HIGH resets to bootloader.
CHIP_PU is the ESP32's enable/reset pin. It must be pulled high to turn the ESP32 on.

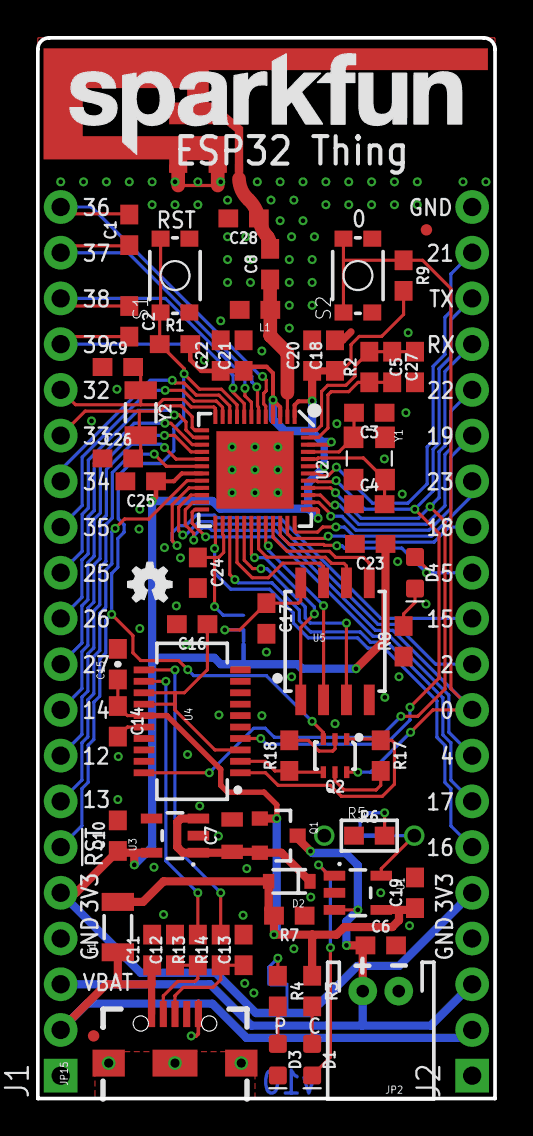
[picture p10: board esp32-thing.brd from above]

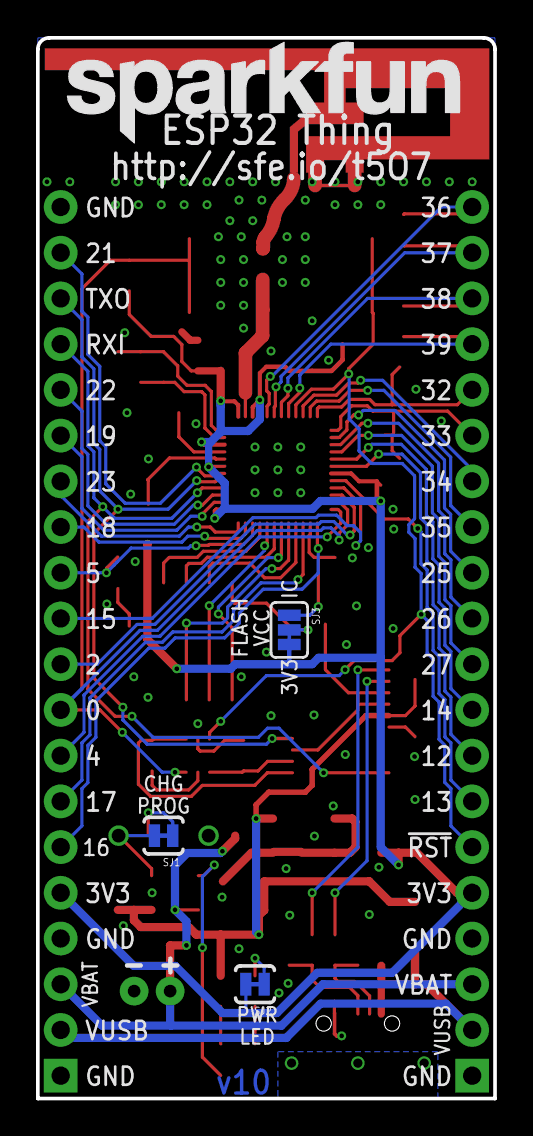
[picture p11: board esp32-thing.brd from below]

Board: 2 copper layers, 25.4 x 58.9 mm, 72 parts (4 on the bottom side), 66 nets.

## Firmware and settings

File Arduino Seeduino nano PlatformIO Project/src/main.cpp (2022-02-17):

#include <anyrtttl.h>
#include <binrtttl.h>
#include <pitches.h>
#include <Adafruit_NeoPixel.h>
#include <Arduino.h>
#include <arduino-timer.h>

#ifdef __AVR__
  #include <avr/power.h>
#endif
#define NeoPixelPIN 12
Adafruit_NeoPixel strip = Adafruit_NeoPixel(12, NeoPixelPIN, NEO_GRB + NEO_KHZ800);
// IMPORTANT: To reduce NeoPixel burnout risk, add 1000 uF capacitor across

#define BUZZER_PIN 10
const char * itchy = "itchy:d=8,o=6,b=160:c,a5,4p";
// This is for Trinket 5V 16MHz, you can remove these three lines if you are not using a Trinket
#if defined (__AVR_ATtiny85__)
  if (F_CPU == 16000000) clock_prescale_set(clock_div_1);
#endif

// IO
const int TouchOnOff = 2; bool TouchOnOffOld = false; bool TouchOnOffPN = false;
const int TouchManAut = 3; bool TouchManAutOld = false; bool TouchManAutPN = false;
const int TouchPlus = 4; bool TouchPlusOld = false; bool TouchPlusPN = false;
const int TouchMinus = 5; bool TouchMinusOld = false; bool TouchMinusPN = false;
const int FlowSensor = 6;
const int MotionSensor = 7;
const int PumpRelay = 9;

// Device States
bool S_OnOff = false;
int Step_Manual = 10;
int Step_Automatic = 20;
bool S_ManAut = false;
int Step_Menu = 30;
bool S_Menu = false;
int Step_Error = 40;
bool S_Error = false;
// Alarms
bool NoWaterFlow = false;

// Timers
unsigned long DelayStartPump = 0;
bool DelayRunningPump = false;
unsigned long DelayStartSettings = 0;
bool DelayRunningSettings = false;

// Settings
int PumpSetting = 2;

void setup() {
  pinMode(BUZZER_PIN, OUTPUT);
  Serial.begin(9600);
  pinMode(TouchOnOff, INPUT);
  pinMode(TouchManAut, INPUT);
  pinMode(TouchPlus, INPUT);
  pinMode(TouchMinus, INPUT);
  pinMode(FlowSensor, INPUT);
  pinMode(MotionSensor, INPUT);
  pinMode(PumpRelay, OUTPUT);

  strip.begin();
  strip.setBrightness(50);
  strip.show(); // Initialize all pixels to 'off'
  
}

void loop() {
  //Button Check
  //if (digitalRead(TouchOnOff)==1) {Serial.write("ON ");} 
  //if (digitalRead(TouchManAut)==1) {Serial.write("MAN ");}
  //if (digitalRead(TouchPlus)==1) {Serial.write("PLUS ");}
  //if (digitalRead(TouchMinus)==1) {Serial.write("MINUS ");}
  //if (digitalRead(MotionSensor)==1) {Serial.write("MOTION ");}
  //if (S_Menu==false) {Serial.write(S_Menu ? "ON " : "OFF ");}
  
  // On Off
  if ((digitalRead(TouchOnOff)==0) && (TouchOnOffOld==1)) 
    {TouchOnOffPN = 1;}
  else {TouchOnOffPN = 0;}
  TouchOnOffOld = digitalRead(TouchOnOff);

  if (S_OnOff==true) {
  // Manual
  if ((digitalRead(TouchManAut)==0) && (TouchManAutOld==1)) 
    {TouchManAutPN = 1;}
  else {TouchManAutPN = 0;}
  TouchManAutOld = digitalRead(TouchManAut);
  
  // Plus
  if ((digitalRead(TouchPlus)==0) && (TouchPlusOld==1)) 
    {TouchPlusPN = 1;}
  else {TouchPlusPN = 0;}
  TouchPlusOld = digitalRead(TouchPlus);
  
  // Minus
  if ((digitalRead(TouchMinus)==0) && (TouchMinusOld==1)) 
    {TouchMinusPN = 1;}
  else {TouchMinusPN = 0;}
  TouchMinusOld = digitalRead(TouchMinus);
  }
  else {
  //Powerled
    strip.setPixelColor(0, strip.Color(255, 225, 255));
    strip.show();
  }

  // BUTTONS
  if (TouchOnOffPN==1) {OnOff();}
  if ((S_Menu==false) && (TouchManAutPN==1)) {Man_Aut();}
  if ((S_Menu==false) && (TouchPlusPN==1)) {Settings();}
  if ((S_Menu==true) && (TouchPlusPN==1)) {Plus();}
  if ((S_Menu==false) && (TouchMinusPN==1)) {Settings();}
  if ((S_Menu==true) && (TouchMinusPN==1)) {Minus();}

  // Automatic Functionality
  if ((S_OnOff==true) && (S_Menu == false) && (S_ManAut == true)) {Automatic();}

  // Manual Functionality
  if ((S_OnOff==true) && (S_Menu == false) && (S_ManAut == false)) {Manual();}
  
  checkTurnOffPump();
  checkTurnOffSettings();

  // Motion indication
  if ((digitalRead(MotionSensor)==true) && (S_OnOff==true)){
    strip.setPixelColor(0, strip.Color(0,255,0));
    strip.show();
  }
  else if (S_OnOff==true) {
    if (S_ManAut==0) {
      strip.setPixelColor(0, strip.Color(233, 225, 85));
      strip.show();
    }
    else {
      strip.setPixelColor(0, strip.Color(0,0,127));
      strip.show();
    }
  }
  
  // Pump indication
  if (digitalRead(PumpRelay)==true) {
    strip.setPixelColor(1, strip.Color(0,255,0));
    strip.show();
  }
  else if (S_OnOff==true) {
    if (S_ManAut==0) {
      strip.setPixelColor(1, strip.Color(233, 225, 85));
      strip.show();
    }
    else {
      strip.setPixelColor(1, strip.Color(0,0,127));
      strip.show();
    }
  }
}
//----------------------------------------------------------

// OnOff Button Code
void OnOff () {
  if (S_OnOff==0) {
    S_OnOff = 1;
    colorWipeAll(strip.Color(0, 0, 127), 50); // Soft Blue
    S_ManAut = true;
  }
  else {
    S_OnOff = false;
    All_Off ();
  }
}

// All Off
void All_Off (){
  digitalWrite(PumpRelay, false);
  S_ManAut = false;
  Step_Manual = 10;
  Step_Automatic = 20;
  S_Menu = false;
  Step_Menu = 40;
  colorWipeAll(strip.Color(0, 0, 0), 50); // Off
}

// Manual-Automatic
void Man_Aut (){
   if ((S_OnOff==1) && (S_Menu==0)) {
    if (S_ManAut==1) 
      {S_ManAut = 0; Manual ();}
    else {S_ManAut = 1;digitalWrite(PumpRelay, false);}
  }
}

// Manual Code
void Manual (){
  colorWipe(strip.Color(233, 225, 85), 50);
  digitalWrite(PumpRelay, true);
}

// Automatic Code
void Automatic (){
  colorWipe(strip.Color(0, 0, 127), 70);
  if (digitalRead(MotionSensor)==1) {
    DelayStartPump = millis();
    DelayRunningPump = true;
    digitalWrite(PumpRelay, true);
    }
}

// Settings Code
void Settings (){
  for(int i=2;i<strip.numPixels();i++){
    strip.setPixelColor(i, strip.Color(0,0,0));
    strip.show();
  }
  for(int i=2;i<PumpSetting;i++){
    strip.setPixelColor(i, strip.Color(255,255,255));
    strip.show();
  }
  DelayStartSettings = millis();
  DelayRunningSettings = true;
  S_Menu = true;
}
void Plus (){
  if (PumpSetting < 12) {
    PumpSetting = PumpSetting + 1;
    DelayStartSettings = millis();
    for(int i=2;i<PumpSetting;i++) {
      strip.setPixelColor(i, strip.Color(255,255,255));
      strip.show();
    }
  }
}
void Minus (){
  if (PumpSetting > 3) {
    PumpSetting = PumpSetting - 1;
    DelayStartSettings = millis();
    for(int i=PumpSetting;i<strip.numPixels();i++) {
      strip.setPixelColor(i, strip.Color(0,0,0));
      strip.show();
    }
  }
}

// Timer delay Pump
void checkTurnOffPump() {
  // check if delay has timed out
  if (DelayRunningPump && ((millis() - DelayStartPump) >= ((PumpSetting-1) * 120000))) { // 2min per led
    DelayRunningPump = false;
    digitalWrite(PumpRelay, false);
    strip.setPixelColor(0, strip.Color(0,0,0));
    strip.show();
  }
}

// Timer delay Settings
void checkTurnOffSettings() {
  // check if delay has timed out
  if (DelayRunningSettings && ((millis() - DelayStartSettings) >= 4000)) {
    DelayRunningSettings = false;
    S_Menu = false;
  }
}

//NeoPixel Codes-------------------------------------------------
void colorWipe(uint32_t c, uint8_t wait) {
  for(uint16_t i=2; i<strip.numPixels(); i++) {
    strip.setPixelColor(i, c);
    strip.show();
    delay(wait);
  }
}
void colorWipeAll(uint32_t c, uint8_t wait) {
  for(uint16_t i=0; i<strip.numPixels(); i++) {
    strip.setPixelColor(i, c);
    strip.show();
    delay(wait);
  }
}

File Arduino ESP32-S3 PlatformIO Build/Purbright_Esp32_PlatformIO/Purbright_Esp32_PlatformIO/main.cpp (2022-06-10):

#include <defines.hpp>

void setup()
{
  Serial.begin(115200);

  // Set GPIO 2 as an OUTPUT
  Serial.println("This is a test print");
  pinMode(LED_BUILTIN, OUTPUT);
  digitalWrite(LED_BUILTIN, LOW);
  Serial.println(F("Booting up"));
  Serial.println("Version: " + String(VERSION) + " " + String(__DATE__));
  Serial.println("");
  Serial.println(F("Starting..."));

  // Setup the network stack
  // Setup the Wifi Manager
  Serial.println(F("Reading Config File"));
  Serial.println(F("Config File Read"));
  Serial.println(F("Setting up WiFi"));
  Serial.println(F("Starting Webserver"));
  timedTasks.SetupTimers();
  Relay.SetupRelays();
  // network.SetupmDNSServer(); // setup the mDNS server for the future web-front-end
  network.SetupServer();
  network.SetupWebServer(); // Setup the server
  // network.DiscovermDNSBroker(); // discover the mDNS broker for mqtt

  Serial.println('\n');
  neopixel.begin();
  networkntp.NTPSetup();
  pump.SetupPumpClass();
  buttons.SetupButtons();
  pir.SetupPIR();
  accumulatedata.begin(&pir);
  accumulatedata.addSelf();
  // purrMqtt.MQTTSetup();

  Serial.println(F("Setup Complete"));
}

void loop()
{
  pump.PumpLoop(); // Setup the main loop for the pump
  pir.run();       // Setup the main loop for the PIR sensor
  buttons.ButtonLoop(); // Setup the main loop for the buttons
  pump.checkTurnOffPump();
  // Automatic Functionality
  if (S_OnOff && !S_Menu && S_ManAut)
  {
    pump.Automatic();
  }

  // Manual Functionality
  if (S_OnOff && !S_Menu && !S_ManAut)
  {
    pump.Manual();
  }
  
  // network.SetupmDNSLoop(); // Setup mDNS loop
  theList.execute();
  timedTasks.checkTurnOffSettings();
  timedTasks.Run_Check_DataJSON_5();
  delay(100);
  timedTasks.checkNetwork();
  // purrMqtt.RunMqttService(); // Run the MQTT service loop
}

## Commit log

2022-02-17 update code
    Full Refactor of project
    [Overview.xlsx, esp32-thing.brd, esp32-thing.kicad_pcb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]
2022-06-07 update
    - Fix buttons class with state management enum

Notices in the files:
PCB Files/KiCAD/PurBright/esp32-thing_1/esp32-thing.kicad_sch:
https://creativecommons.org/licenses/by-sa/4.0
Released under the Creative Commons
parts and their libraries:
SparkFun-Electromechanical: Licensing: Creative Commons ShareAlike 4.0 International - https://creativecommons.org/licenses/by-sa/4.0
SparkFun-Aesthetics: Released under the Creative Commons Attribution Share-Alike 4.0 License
